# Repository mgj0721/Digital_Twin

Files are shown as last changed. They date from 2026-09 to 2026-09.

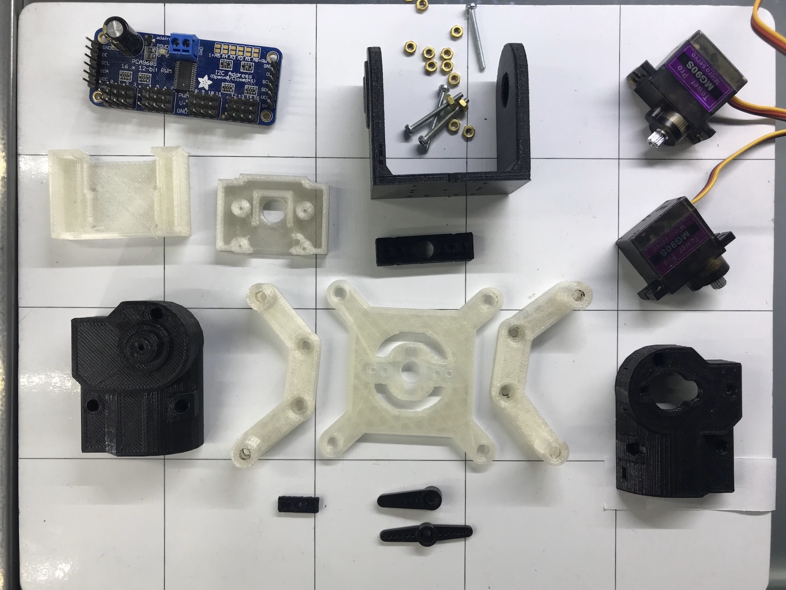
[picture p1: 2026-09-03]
PanTilt4.jpg

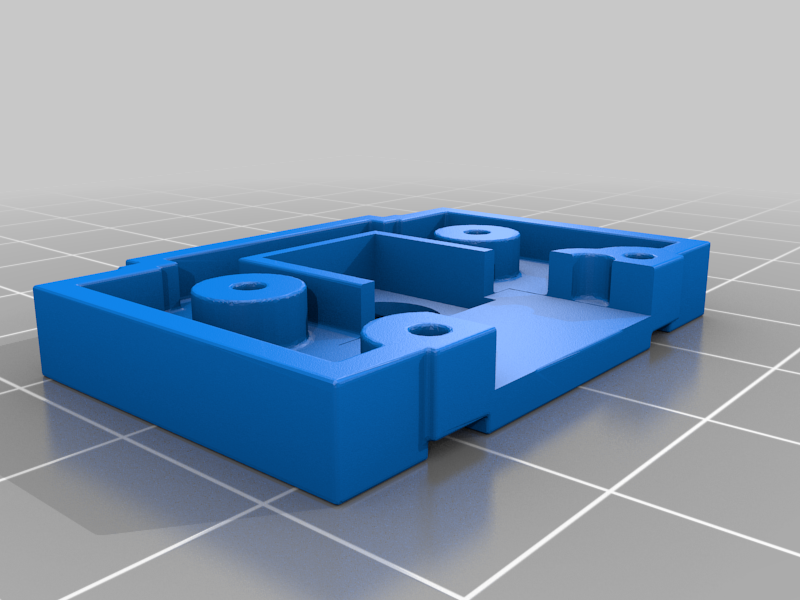
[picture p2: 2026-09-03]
PanTilt_Cameratop.png

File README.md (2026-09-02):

# Digital_Twin

이동형 검사 모듈로 선체 표면을 촬영하면, Jetson Nano가 YOLOv5로 부식을 찾아내고
ArUco 마커로 위치를 계산해서 Unity 3D 디지털 트윈 위에 실시간으로 표시해준다.
하기는 시스템 아케텍처와 각 폴더별 역할, 데이터의 흐름과 실행 순서를 상술했다.
## 1. 전체 아키텍처

```mermaid
flowchart LR
    subgraph Field["실제 선체 표면"]
        Cam["카메라\n(이동형 검사 모듈)"]
    end

    subgraph JetsonBox["Jetson Nano — Jetson_package/"]
        YOLO["YOLOv5 (TensorRT)\n부식 탐지"]
        ArUco["ArUco 인식 +\nhomography 계산\n(u, v 좌표 변환)"]
        WSClient["WebSocket 클라이언트\n(\"JETSON\"으로 식별)"]
        Flask["Flask 웹 컨트롤러\n(모듈 원격 조종 UI)"]
    end

    subgraph ArduinoBox["Arduino — Arduino/"]
        Motor["DC 모터 + 서보\n(이동 / 팬틸트)"]
    end

    subgraph LaptopBox["노트북 — Laptop_server/"]
        Relay["WebSocket 서버\n(중계 전용)"]
    end

    subgraph UnityBox["Unity PC — Unity_Script/"]
        Receiver["JetsonWebSocketReceiver.cs\nWS 클라이언트 + JSON 파싱"]
        Visualizer["DigitalTwinDetectionVisualizer.cs\n2D bbox 미리보기 (conf ≥ 0.50)"]
        Mapper["SurfaceMarkerMapper.cs\n3D Marker 배치 (conf ≥ 0.70)"]
    end

    Cam --> YOLO
    Cam --> ArUco
    YOLO --> WSClient
    ArUco --> WSClient
    Flask <--> Motor
    WSClient -- "detection_frame JSON\n(WebSocket)" --> Relay
    Relay -- "JETSON → UNITY 중계" --> Receiver
    Receiver --> Visualizer
    Receiver --> Mapper
```

`yolo/` 폴더는 이 실시간 파이프라인에는 안 들어간다. Jetson에 올라가는 모델
(`best.pt`/엔진 파일)을 만들어낸 **학습 과정**(Colab)을 따로 담아둔 폴더다.

## 2. 폴더별 역할

| 폴더 | 실행 위치 | 역할 |
| --- | --- | --- |
| **`Arduino/`** | 이동형 검사 모듈에 장착된 Arduino | Jetson의 Flask 컨트롤러가 시리얼로 보내는 명령을 받아 실제로 모듈을 움직인다. L298N 드라이버로 DC 모터 2개를 제어해서 전후좌우 이동(W/A/S/D)을, 서보모터 2개로 카메라 팬/틸트(I/J/K/L, C는 중앙 정렬)를 맡는다. 명령이 300ms 넘게 안 들어오면 자동으로 멈추는 안전장치도 들어있다. |
| **`Jetson_package/`** | Jetson Nano | 카메라 프레임을 받아서 ① TensorRT로 최적화한 YOLOv5로 부식을 탐지하고, ② ArUco 마커를 인식해서 homography를 계산해 탐지 위치를 표면 좌표(u, v)로 바꾸고, ③ 그 결과를 표준 JSON으로 묶어 WebSocket으로 노트북에 보낸다. 모듈을 원격 조종하는 Flask 웹 UI도 여기서 같이 돌아간다. |
| **`Laptop_server/`** | 노트북 (Jetson·Unity와 같은 Wi-Fi) | 딱 WebSocket **중계**만 하는 서버. Jetson과 Unity가 각각 접속해서 첫 메시지로 자기가 누군지 밝히면(“JETSON”/“UNITY”), Jetson이 보낸 탐지 결과를 그대로 Unity로 넘겨준다. |
| **`Unity_Script/`** | Unity PC | 중계받은 JSON을 디지털 트윈에 실제로 반영하는 부분. `JetsonWebSocketReceiver.cs`가 수신과 역직렬화를 맡고, `DigitalTwinDetectionVisualizer.cs`는 화면에 2D 박스로 미리 보여주고, `SurfaceMarkerMapper.cs`는 표면 좌표(u, v)를 3D 모델 위 실제 위치로 바꿔서 부식 Marker를 배치한다. |
| **`yolo/`** | 학습용 (Colab, Jetson과는 별개) | 실제로 쓰이는 YOLOv5 모델을 학습시킨 원본 코드와 데이터 정의. 지금 학습된 모델은 **corrosion(부식) 단일 클래스**만 탐지한다. |

## 3. 데이터가 흘러가는 경로

```
카메라 프레임
  → YOLOv5(TensorRT) 추론 → bbox + confidence + label
  → ArUco 마커 인식 → homography 계산 → bbox 중심점을 표면 좌표(u, v)로 변환
  → 표준 JSON(detection_frame)으로 조립
  → WebSocket 전송: Jetson → 노트북(중계) → Unity
  → Unity에서 confidence 기준으로 2D 미리보기 / 3D 확정 배치로 나뉨
```

Jetson과 Unity가 주고받는 메시지는 이런 구조를 쓴다 (`detection_frame`):

```json
{
  "type": "detection_frame",
  "schemaVersion": 1,
  "source": "yolov5",
  "sequence": 8015,
  "sentAtUnixMs": 1780000000000,
  "camera": { "width": 1280, "height": 720 },
  "detections": [
    {
      "id": "det-0",
      "label": "corrosion",
      "confidence": 0.78,
      "bbox": { "x": 191, "y": 326, "width": 250, "height": 69 },
      "surface": { "id": "foam-board-front", "u": 0.42, "v": 0.68 }
    }
  ]
}
```

- `bbox`는 이미지 픽셀 좌표고, `surface.u`/`v`는 ArUco 마커로 계산한 **표면 위 상대 좌표(0~1)**다.
- 그 프레임에서 ArUco 마커가 인식되지 않으면 `surface` 필드는 아예 안 붙는다 — 이때도 2D 박스는 계속 뜨고, 3D Marker만 그 프레임에서 안 찍힌다.
- `confidence`는 두 단계로 쓴다: 2D 화면 미리보기는 `≥ 0.50`, 3D 디지털 트윈 확정 배치는 `≥ 0.70`.

## 4. 실행 순서

1. **노트북**: `Laptop_server/`의 WebSocket 서버부터 켜둔다 (Jetson·Unity가 붙을 준비 상태로).
2. **Jetson Nano**: `Jetson_package/`의 메인 스크립트를 실행하면 카메라·YOLOv5·ArUco·Arduino 제어가 한 번에 시작된다. 실행 전 노트북의 Wi-Fi IP를 코드 안 접속 주소에 맞게 바꿔줘야 한다.
3. **Unity**: `Unity_Script/`가 붙은 씬을 Play. `JetsonWebSocketReceiver`의 Laptop Ip/Port를 노트북 IP에 맞추고, `SurfaceMarkerMapper`의 Surface Planes에 검사 대상 표면(앞면/뒷면 등)의 기준점을 미리 등록해둬야 3D Marker가 실제로 배치된다.
4. **Arduino**: `Arduino/`의 스케치를 업로드해서 이동형 검사 모듈에 연결한다. 이후엔 Jetson의 Flask 컨트롤러(웹 브라우저)로 원격 조종한다.

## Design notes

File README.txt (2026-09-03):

Raspicam Pan/Tilt for MG90 servos by charliejgallo on Thingiverse: https://www.thingiverse.com/thing:3891807

Summary:
PanTilt for Raspberry pi Camera module (v1/v2) and MG90S servosremixed and edited modeloptional base for pca9685 includedPrint body A and B with supportsParts:2x MG90S servossome extra M2 screws and boltsall the screws from the MG90S servos4x 10mm M4 screws

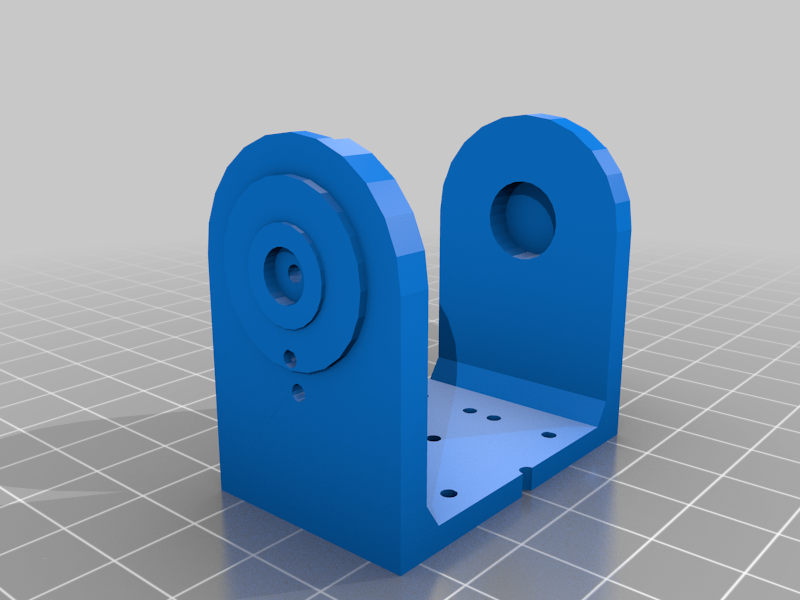
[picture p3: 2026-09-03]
PanTilt_Arm.png

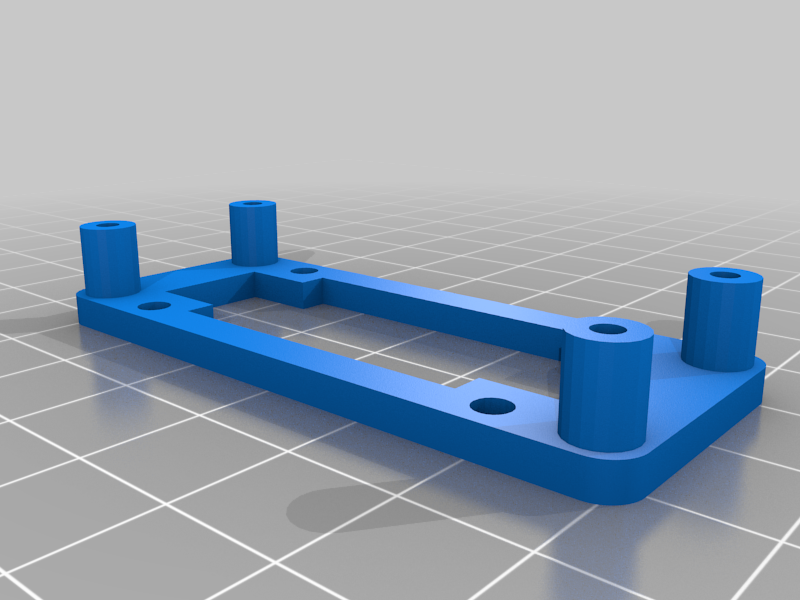
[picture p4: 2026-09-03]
PanTilt_pca9685.png

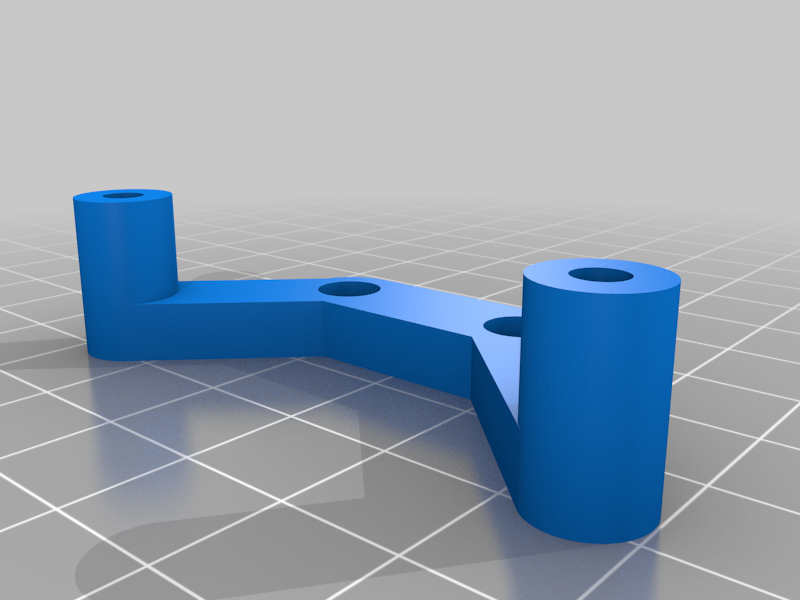
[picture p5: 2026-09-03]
PanTilt_Feet.png

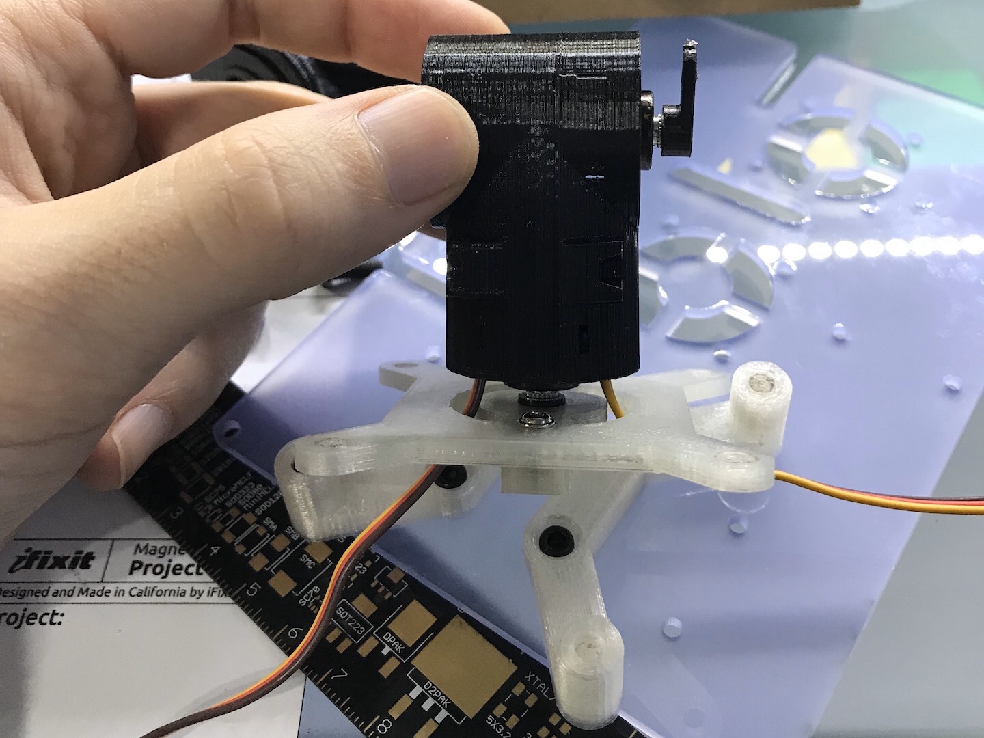
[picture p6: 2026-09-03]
PanTilt3.jpg

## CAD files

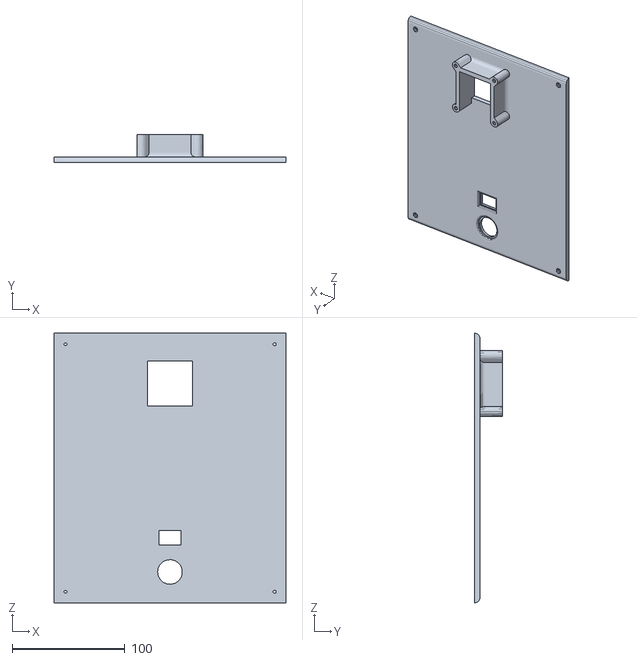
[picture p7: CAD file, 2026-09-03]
top.stl
206.0 x 25.0 x 240.0

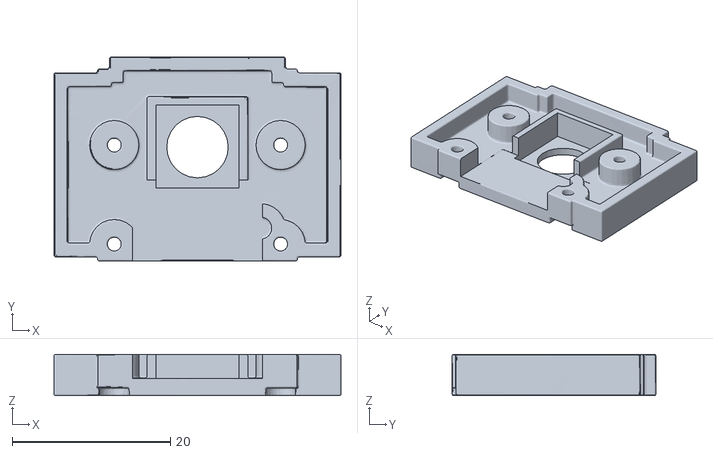
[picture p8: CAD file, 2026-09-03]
PanTilt_Cameratop.stl
36.2 x 25.7 x 5.23

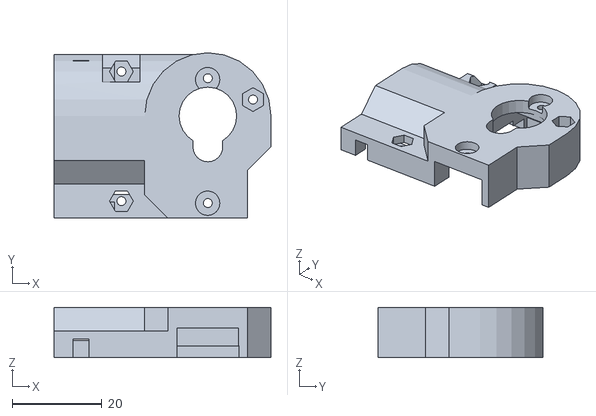
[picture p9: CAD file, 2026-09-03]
PanTilt_Body-A.stl
48.3 x 36.8 x 11.2

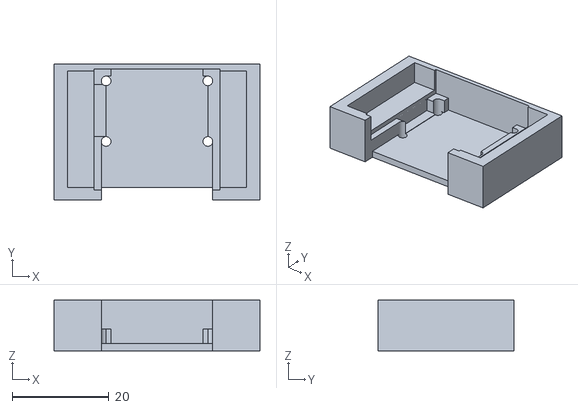
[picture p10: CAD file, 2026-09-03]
PanTilt_Camerabottom.stl
42.5 x 28.1 x 10.5

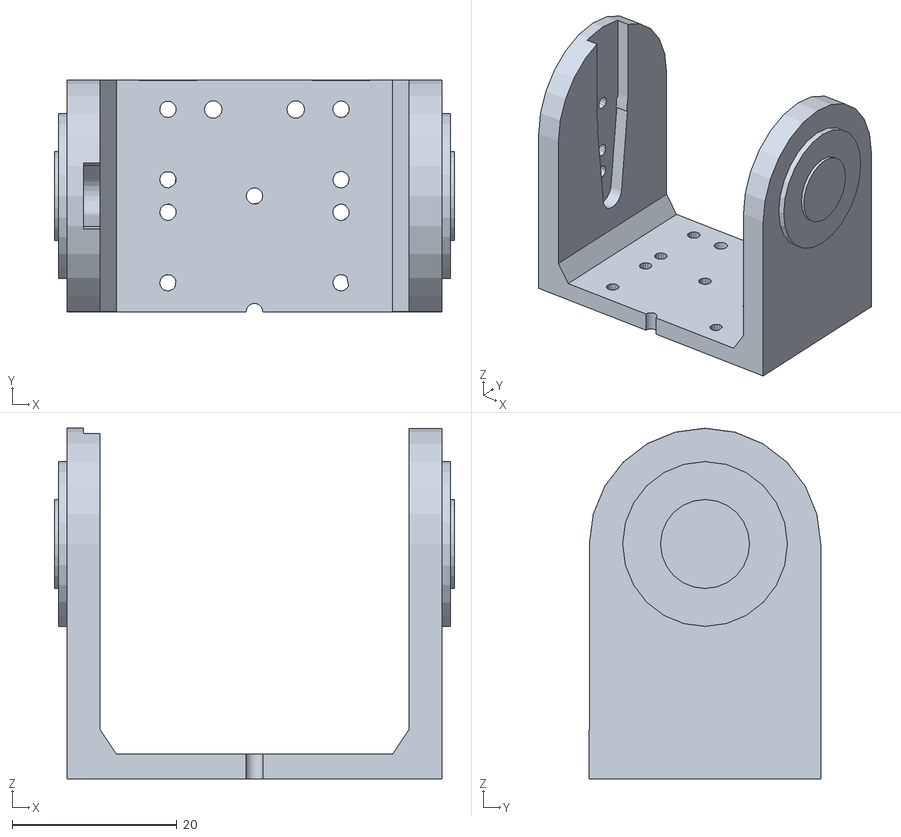
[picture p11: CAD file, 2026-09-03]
PanTilt_Arm.stl
48.5 x 28.1 x 42.5

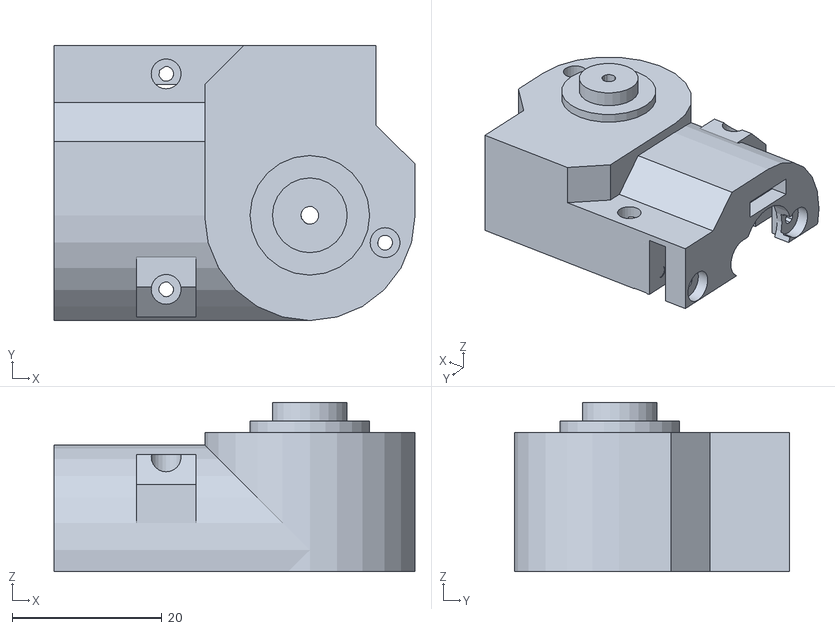
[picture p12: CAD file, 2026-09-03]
PanTilt_Body-B.stl
48.3 x 36.8 x 22.6

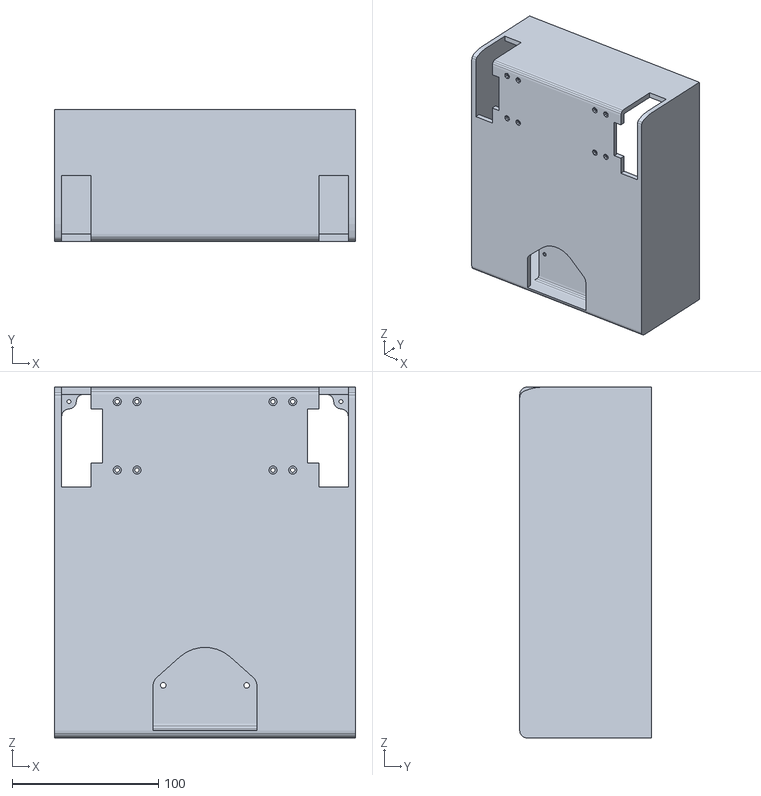
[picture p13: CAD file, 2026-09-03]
bottom.stl
206.0 x 90.0 x 240.0

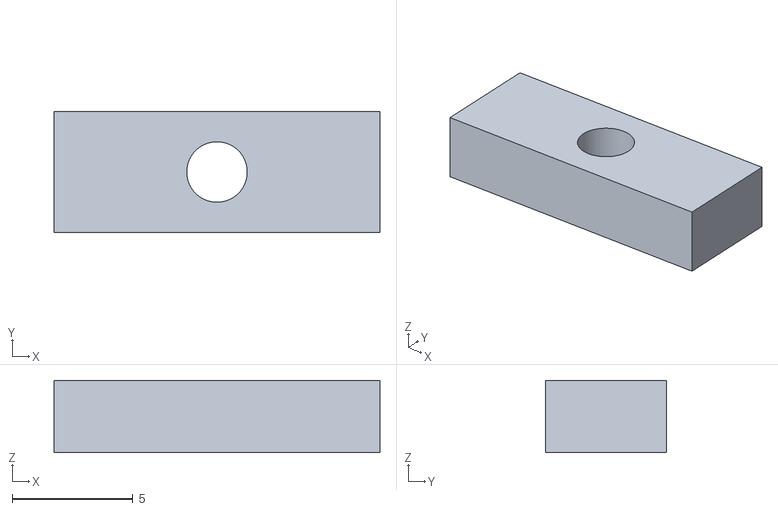
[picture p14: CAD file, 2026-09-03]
PanTilt_Block.stl
13.5 x 5.00 x 3.00

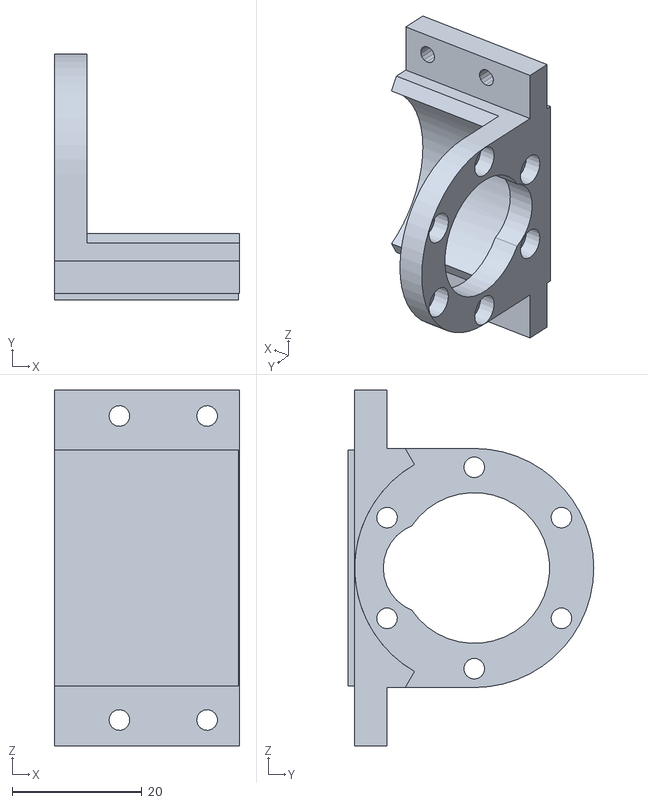
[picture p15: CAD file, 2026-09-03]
motor_base.stl
28.5 x 37.8 x 54.8

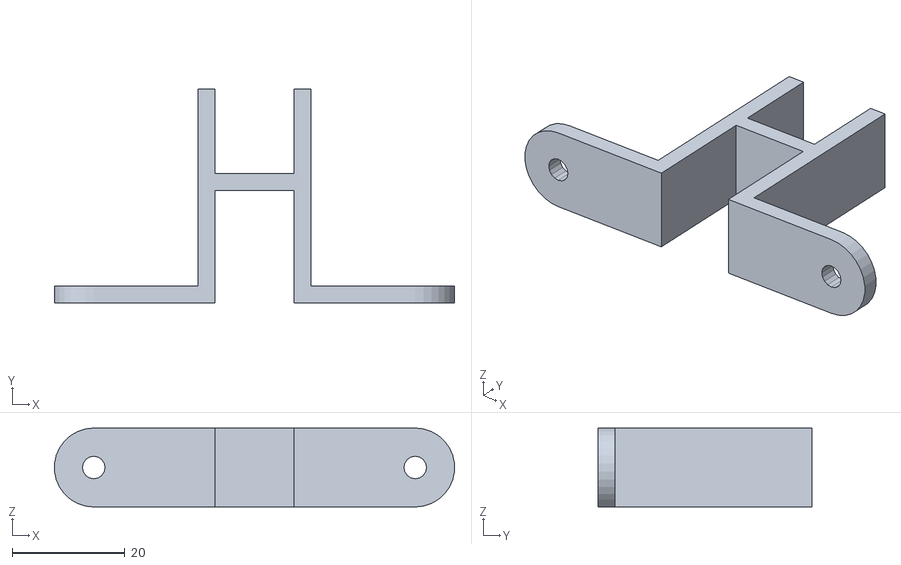
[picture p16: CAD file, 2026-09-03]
accessory.stl
70.9 x 38.0 x 14.0

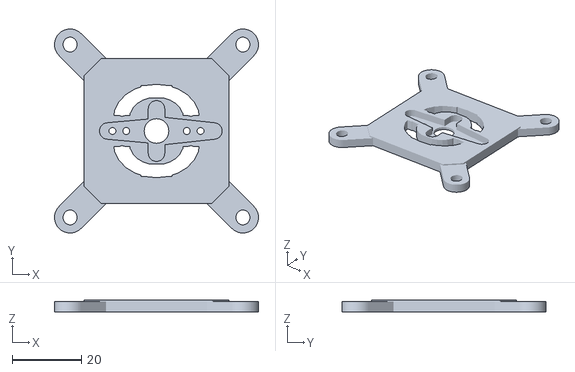
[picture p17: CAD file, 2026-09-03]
PanTilt_Base_kai.stl
59.0 x 59.0 x 3.50

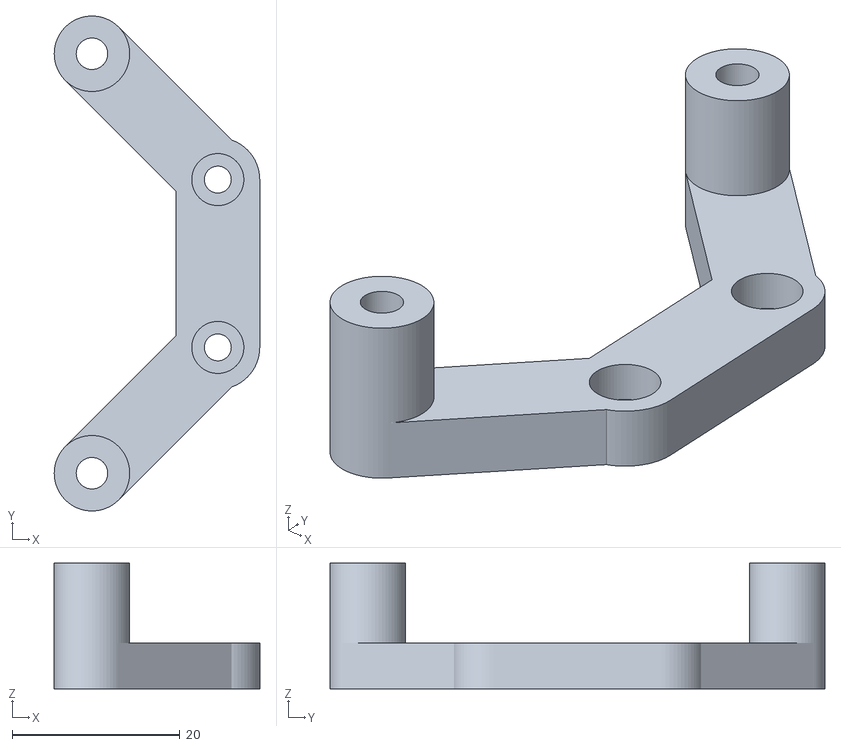
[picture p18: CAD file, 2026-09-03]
PanTilt_Feet.stl
24.5 x 59.0 x 15.0

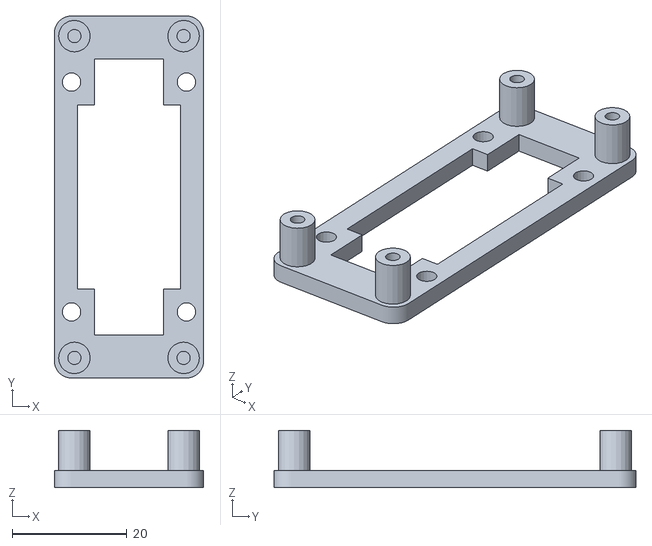
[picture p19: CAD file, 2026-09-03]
PanTilt_pca9685.stl
26.0 x 63.0 x 10.0

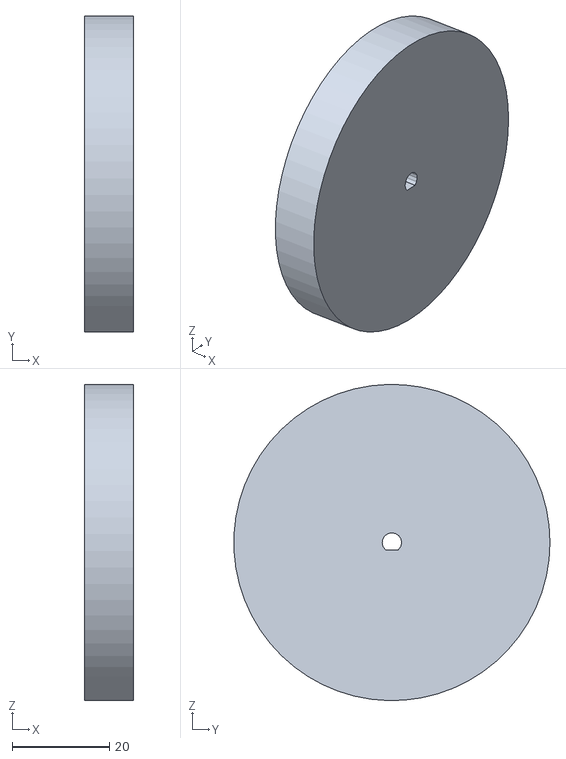
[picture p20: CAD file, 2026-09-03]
wheel.stl
10.0 x 65.0 x 65.0

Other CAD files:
PanTilt_Baselock.stl
PanTilt_Base.stl

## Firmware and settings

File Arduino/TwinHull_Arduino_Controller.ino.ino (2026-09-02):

#include <Servo.h>

// =====================================================
// L298N - DC Motor
// =====================================================

// Motor A
const int ENA = 3;
const int IN1 = 5;
const int IN2 = 6;

// Motor B
const int ENB = 11;
const int IN3 = 7;
const int IN4 = 8;

// DC Motor PWM Speed
const int MOTOR_SPEED = 150;

// Motor safety timeout
const unsigned long MOTOR_TIMEOUT = 300;

// 마지막 모터 명령을 받은 시간
unsigned long lastMotorCommandTime = 0;


// =====================================================
// Servo
// =====================================================

Servo panServo;
Servo tiltServo;

const int PAN_PIN  = 9;
const int TILT_PIN = 10;


// =====================================================
// Pan Servo
// 0° ~ 180°
// =====================================================

const int PAN_CENTER = 90;
const int PAN_MIN = 0;
const int PAN_MAX = 180;

int panAngle = PAN_CENTER;


// =====================================================
// Tilt Servo
// 60° ~ 120°
// =====================================================

const int TILT_CENTER = 90;
const int TILT_MIN = 60;
const int TILT_MAX = 120;

int tiltAngle = TILT_CENTER;


// =====================================================
// Servo movement step
// =====================================================

const int SERVO_STEP = 1;


// =====================================================
// Setup
// =====================================================

void setup() {

  // DC Motor
  pinMode(ENA, OUTPUT);
  pinMode(IN1, OUTPUT);
  pinMode(IN2, OUTPUT);

  pinMode(ENB, OUTPUT);
  pinMode(IN3, OUTPUT);
  pinMode(IN4, OUTPUT);

  stopMotor();


  // Servo
  panServo.attach(PAN_PIN);
  tiltServo.attach(TILT_PIN);

  // Pan 중앙
  panServo.write(panAngle);

  // Tilt 중앙
  tiltServo.write(tiltAngle);


  // UART
  Serial.begin(115200);


  // 시작 시 안전 상태
  lastMotorCommandTime = millis();
}


// =====================================================
// Main Loop
// =====================================================

void loop() {

  // ---------------------------------------------------
  // Serial Command
  // ---------------------------------------------------

  if (Serial.available() > 0) {

    char command = Serial.read();

    switch (command) {

      // -----------------------------------------------
      // DC Motor
      // -----------------------------------------------

      case 'W':
      case 'w':
        forward();
        lastMotorCommandTime = millis();
        break;


      case 'S':
      case 's':
        backward();
        lastMotorCommandTime = millis();
        break;


      case 'A':
      case 'a':
        left();
        lastMotorCommandTime = millis();
        break;


      case 'D':
      case 'd':
        right();
        lastMotorCommandTime = millis();
        break;


      case 'X':
      case 'x':
        stopMotor();
        lastMotorCommandTime = millis();
        break;


      // -----------------------------------------------
      // Pan
      //
      // 실제 카메라 장착 방향 때문에
      // J / L 방향 반전
      // -----------------------------------------------

      case 'J':
      case 'j':
        panRight();
        break;


      case 'L':
      case 'l':
        panLeft();
        break;


      // -----------------------------------------------
      // Tilt
      //
      // 실제 카메라 장착 방향에 맞춰
      // I / K 방향 반전
      // -----------------------------------------------

      case 'I':
      case 'i':
        tiltUp();
        break;


      case 'K':
      case 'k':
        tiltDown();
        break;


      // -----------------------------------------------
      // Pan / Tilt Center
      // -----------------------------------------------

      case 'C':
      case 'c':
        centerServo();
        break;
    }
  }


  // ---------------------------------------------------
  // Motor Safety Timeout
  // ---------------------------------------------------

  if (millis() - lastMotorCommandTime > MOTOR_TIMEOUT) {
    stopMotor();
  }
}


// =====================================================
// DC Motor
// =====================================================

// Forward
void forward() {

  digitalWrite(IN1, HIGH);
  digitalWrite(IN2, LOW);

  digitalWrite(IN3, HIGH);
  digitalWrite(IN4, LOW);

  analogWrite(ENA, MOTOR_SPEED);
  analogWrite(ENB, MOTOR_SPEED);
}


// =====================================================
// Backward
// =====================================================

void backward() {

  digitalWrite(IN1, LOW);
  digitalWrite(IN2, HIGH);

  digitalWrite(IN3, LOW);
  digitalWrite(IN4, HIGH);

  analogWrite(ENA, MOTOR_SPEED);
  analogWrite(ENB, MOTOR_SPEED);
}


// =====================================================
// Left
// =====================================================

void left() {

  digitalWrite(IN1, LOW);
  digitalWrite(IN2, HIGH);

  digitalWrite(IN3, HIGH);
  digitalWrite(IN4, LOW);

  analogWrite(ENA, MOTOR_SPEED);
  analogWrite(ENB, MOTOR_SPEED);
}


// =====================================================
// Right
// =====================================================

void right() {

  digitalWrite(IN1, HIGH);
  digitalWrite(IN2, LOW);

  digitalWrite(IN3, LOW);
  digitalWrite(IN4, HIGH);

  analogWrite(ENA, MOTOR_SPEED);
  analogWrite(ENB, MOTOR_SPEED);
}


// =====================================================
// Stop
// =====================================================

void stopMotor() {

  analogWrite(ENA, 0);
  analogWrite(ENB, 0);

  digitalWrite(IN1, LOW);
  digitalWrite(IN2, LOW);

  digitalWrite(IN3, LOW);
  digitalWrite(IN4, LOW);
}


// =====================================================
// Pan Servo
// =====================================================

void panLeft() {

  if (panAngle > PAN_MIN) {

    panAngle -= SERVO_STEP;

    if (panAngle < PAN_MIN) {
      panAngle = PAN_MIN;
    }

    panServo.write(panAngle);
  }
}


// =====================================================
// Pan Right
// =====================================================

void panRight() {

  if (panAngle < PAN_MAX) {

    panAngle += SERVO_STEP;

    if (panAngle > PAN_MAX) {
      panAngle = PAN_MAX;
    }

    panServo.write(panAngle);
  }
}


// =====================================================
// Tilt Servo
// =====================================================
// 실제 동작 기준으로 방향을 반전함.
//
// I → tiltUp() → 각도 감소 → 실제 위로
// K → tiltDown() → 각도 증가 → 실제 아래로
// =====================================================

void tiltUp() {

  if (tiltAngle > TILT_MIN) {

    tiltAngle -= SERVO_STEP;

    if (tiltAngle < TILT_MIN) {
      tiltAngle = TILT_MIN;
    }

    tiltServo.write(tiltAngle);
  }
}


// =====================================================
// Tilt Down
// =====================================================

void tiltDown() {

  if (tiltAngle < TILT_MAX) {

    tiltAngle += SERVO_STEP;

    if (tiltAngle > TILT_MAX) {
      tiltAngle = TILT_MAX;
    }

    tiltServo.write(tiltAngle);
  }
}


// =====================================================
// Center Pan / Tilt
// =====================================================

void centerServo() {

  // Pan 중앙 = 90°
  panAngle = PAN_CENTER;

  // Tilt 중앙 = 90°
  tiltAngle = TILT_CENTER;

  panServo.write(panAngle);
  tiltServo.write(tiltAngle);
}

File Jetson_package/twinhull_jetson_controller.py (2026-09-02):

#!/usr/bin/env python3
# -*- coding: utf-8 -*-
# TwinHull Jetson Nano 통합 제어 프로그램
#
# 기존 detect_working_websocket.py + web_controller.py 통합본
#
# 유지되는 구조:
#   Jetson
#   ├── IMX219 Camera -> TensorRT YOLO -> Detection
#   │                                      └-> WebSocket Client -> Laptop:5000
#   │
#   └── Flask:5000 -> Browser -> Arduino Serial /dev/ttyUSB0
#
# WebSocket:
#   Jetson -> Laptop
#   IP   : <LAPTOP_LAN_IP>   # TODO: 아래 LAPTOP_IP 와 동일한 값으로 채우세요 (예: 192.168.0.25)
#   Port : 5000
#
# Flask:
#   Jetson 0.0.0.0:5000
#
# Arduino:
#   /dev/ttyUSB0 @ 115200

import time
import ctypes
import json
import asyncio
import threading
import queue

import numpy as np
import cv2
import tensorrt as trt
import pycuda.driver as cuda
import pycuda.autoinit  # noqa: F401
import websockets

from flask import Flask, render_template_string
import serial


# =====================================================
# Configuration - Original Values Preserved
# =====================================================

# TODO: TensorRT 엔진(.engine) 파일의 실제 절대경로로 교체하세요.
#       (예: "/home/사용자명/model/best.engine")
ENGINE_PATH = "/home/<YOUR_USERNAME>/model/best.engine"

# Jetson -> Laptop WebSocket
# TODO: 노트북(중계 서버)이 접속된 실제 LAN IP 주소로 교체하세요. (예: "192.168.0.25")
LAPTOP_IP = "<LAPTOP_LAN_IP>"
WEBSOCKET_PORT = 5000
WEBSOCKET_URL = "ws://{}:{}".format(LAPTOP_IP, WEBSOCKET_PORT)
WS_RECONNECT_DELAY = 3.0

# Camera
CAMERA_WIDTH = 1280
CAMERA_HEIGHT = 720
DISPLAY_WIDTH = 1280
DISPLAY_HEIGHT = 720

# TensorRT / YOLO
INPUT_W = 320
INPUT_H = 320

CONF_THRESHOLD = 0.30
NMS_THRESHOLD = 0.45

# [cx, cy, w, h, confidence, class_probability]
OUTPUT_FORMAT = "cxcywh"

# Arduino
ARDUINO_PORT = "/dev/ttyUSB0"
ARDUINO_BAUDRATE = 115200

# Flask
FLASK_HOST = "0.0.0.0"
FLASK_PORT = 5000

TRT_LOGGER = trt.Logger(trt.Logger.WARNING)

# =====================================================
# ArUco -> Surface Mapping
# =====================================================
# 현재 Unity에서 사용하는 surface ID와 동일하게 맞춘다.
#
# Front:
#   ArUco 0,1,2,3
# Back:
#   ArUco 4,5,6,7
#
# 각 면에서 4개의 마커 중심을 다음 순서로 배치한다고 가정:
#   0.0,0.0 = 좌상
#   1.0,0.0 = 우상
#   1.0,1.0 = 우하
#   0.0,1.0 = 좌하
#
# 실제 마커 배치가 다르면 아래 ID 매핑만 수정하면 된다.

SURFACE_MARKER_LAYOUT = {
    "foam-board-front": {
        0: (0.0, 0.0),
        1: (1.0, 0.0),
        2: (1.0, 1.0),
        3: (0.0, 1.0),
    },
    "foam-board-back": {
        4: (0.0, 0.0),
        5: (1.0, 0.0),
        6: (1.0, 1.0),
        7: (0.0, 1.0),
    },
}

MIN_SURFACE_MARKERS = 4


# =====================================================
# GStreamer
# =====================================================

def gstreamer_pipeline(
    capture_width=1280,
    capture_height=720,
    display_width=1280,
    display_height=720,
    framerate=30,
    flip_method=0,
):
    return (
        "nvarguscamerasrc sensor-id=0 ! "
        "video/x-raw(memory:NVMM), "
        "width=(int)%d, height=(int)%d, "
        "format=(string)NV12, framerate=(fraction)%d/1 ! "
        "nvvidconv flip-method=%d ! "
        "video/x-raw, width=(int)%d, height=(int)%d, "
        "format=(string)BGRx ! "
        "videoconvert ! "
        "video/x-raw, format=(string)BGR ! "
        "appsink drop=true max-buffers=1 sync=false"
        % (
            capture_width,
            capture_height,
            framerate,
            flip_method,
            display_width,
            display_height,
        )
    )


# =====================================================
# TensorRT Engine
# =====================================================

class TensorRTEngine:
    def __init__(self, engine_path):
        with open(engine_path, "rb") as f:
            engine_data = f.read()

        runtime = trt.Runtime(TRT_LOGGER)
        self.engine = runtime.deserialize_cuda_engine(engine_data)

        if self.engine is None:
            raise RuntimeError("TensorRT engine을 로드하지 못했습니다.")

        self.context = self.engine.create_execution_context()

        self.input_index = None
        self.output_index = None

        for i in range(self.engine.num_bindings):
            name = self.engine.get_binding_name(i)
            shape = self.engine.get_binding_shape(i)
            dtype = self.engine.get_binding_dtype(i)

            print(
                "Binding {}: name={}, shape={}, dtype={}".format(
                    i, name, shape, dtype
                )
            )

            if self.engine.binding_is_input(i):
                self.input_index = i
            else:
                self.output_index = i

        if self.input_index is None or self.output_index is None:
            raise RuntimeError("입력/출력 binding을 찾지 못했습니다.")

        self.input_shape = tuple(
            self.engine.get_binding_shape(self.input_index)
        )
        self.output_shape = tuple(
            self.engine.get_binding_shape(self.output_index)
        )

        if self.input_shape != (1, 3, INPUT_H, INPUT_W):
            print(
                "주의: 예상 입력 (1,3,320,320), 실제 입력:",
                self.input_shape
            )

        print("Input shape :", self.input_shape)
        print("Output shape:", self.output_shape)

        input_size = trt.volume(self.input_shape)
        output_size = trt.volume(self.output_shape)

        self.input_host = cuda.pagelocked_empty(
            input_size, np.float32
        )
        self.output_host = cuda.pagelocked_empty(
            output_size, np.float32
        )

        self.input_device = cuda.mem_alloc(
            self.input_host.nbytes
        )
        self.output_device = cuda.mem_alloc(
            self.output_host.nbytes
        )

        self.bindings = [0] * self.engine.num_bindings

        self.bindings[self.input_index] = int(
            self.input_device
        )
        self.bindings[self.output_index] = int(
            self.output_device
        )

        self.stream = cuda.Stream()
        self.debug_printed = False

    def infer(self, image):
        # BGR uint8 -> RGB float32 -> [0,1] -> CHW
        resized = cv2.resize(
            image,
            (INPUT_W, INPUT_H),
            interpolation=cv2.INTER_LINEAR
        )

        rgb = cv2.cvtColor(
            resized,
            cv2.COLOR_BGR2RGB
        )

        tensor = rgb.astype(np.float32) / 255.0
        tensor = np.transpose(tensor, (2, 0, 1))
        tensor = np.ascontiguousarray(tensor)

        np.copyto(
            self.input_host,
            tensor.ravel()
        )

        cuda.memcpy_htod_async(
            self.input_device,
            self.input_host,
            self.stream
        )

        self.context.execute_async_v2(
            bindings=self.bindings,
            stream_handle=self.stream.handle,
        )

        cuda.memcpy_dtoh_async(
            self.output_host,
            self.output_device,
            self.stream
        )

        self.stream.synchronize()

        raw = self.output_host.reshape(-1, 6)
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

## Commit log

2026-09-02 Enhance README with system architecture and usage details
    Expanded the README to include detailed system architecture, folder roles, data flow, and execution order for the Digital Twin package.
2026-09-03 Add files via upload
    Digital_Twin_HW
    [PanTilt_Arm.stl, PanTilt_Base.stl, PanTilt_Base_kai.stl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]
